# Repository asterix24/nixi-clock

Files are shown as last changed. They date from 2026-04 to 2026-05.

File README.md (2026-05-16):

# nixi-clock
My personal nixi clock with RP2040 Raspberry pico Zero



## Feature

- 4 Digit IN-4 Nixi Tube
- Raspberry Pico Zero W
- Ambient lighting sensor
- Temperature sensor
- DHT11 Sensor
- FM Radio with SkyLab chip Si470x

# Hardware

## Nixie Tube Driver
The nixie tubes needs high voltage to turn on the filament. Each tube have a commen node (Anode) and the chiper is turn on by a dedicate pin.
To drive the filament there is a dedicate mux, that could be driver with TTL voltage, using 4bit we can select 0-9 chiper.



The high voltage mux driver is connected to the 2 byte SIPO:



# Raspberry Pico WiFi Nixie Clock

| Pin # | Nome Pin (MCU) | Segnale / Net | Resistore | Note |
|---|---|---|---|---|
| 1 | GP0 | GP0 | R139 33R  | |
| 2 | GP1 | GP1 | R140 33R  | |
| 4 | GP2 | GP2 | R141 33R  | |
| 5 | GP3 | GP3 | R142 33R  | |
| 6 | GP4 | BACK_LIGHT_DATA | R100 33R  | |
| 7 | GP5 | FRONT_LIGHT_DATA | R101 33R  | |
| 9 | GP6 | HV_ENABLE | R114 33R  | High voltage boost Enable |
| 10 | GP7 | SIPO_RCLK | R104 33R  | Clock Chiper SIPO|
| 11 | GP8 | SIPO_CLR | R106 33R  | Clock Chiper SIPO|
| 12 | GP9 | SIPO_OE | R108 33R  | Clock Chiper SIPO|
| 14 | GP10 | SIPO_DATA | R111 33R  | Clock Chiper SIPO|
| 15 | GP11 | SIPO_CLK | R113 33R  | Clock Chiper SIPO|
| 16 | GP12 | 1WIRE_SENSOR | R105 33R  | |
| 17 | GP13 | B | R112 33R  | External Encoder  Signal B|
| 19 | GP14 | SWITCH0 | R109 33R  | External Encoder  Button |
| 20 | GP15 | A | R110 33R  | External Encoder  Signal A |
| 21 | GP16 | SDIO | — | |
| 22 | GP17 | SCLK | — | |
| 24 | GP18 | RST | — | |
| 25 | GP19 | GP19 | R144 33R  | |
| 26 | GP20 | BUZZER | R102 33R  | |
| 27 | GP21 | RADIO_SW | — | |
| 29 | GP22 | GP22 | R143 33R  | |
| 30 | RUN | nRESET | R103 33R  | |
| 31 | GP26 | Raw_LOUT | R133 33R  | |
| 32 | GP27 | Raw_ROUT | R132 33R  | |
| 34 | GP28 | AMB_LIGHT | R107 1k | Ambient Light Sensor  |
| 35 | AVREF | — | — | |
| 36 | 3V3 | +3.3V | — | Alimentazione |
| 37 | EN | — | — | Non connesso  |
| 39 | VSYS | — | — | Non connesso  |
| 40 | VBUS | +5V | — | Alimentazione |

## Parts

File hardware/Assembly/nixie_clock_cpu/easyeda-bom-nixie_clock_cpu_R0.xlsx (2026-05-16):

Comment | Designator | Footprint | LCSC Part #（optional）
Name | Designator | Footprint | #Column Name Error:' CODE LCSC
BUZZER | BUZ1 | buzzer_14mm_thd
10uF | C100 | 0603_[1608]
100nF | C101, C102, C105, C106, C107, C112, C113, C114 | 0603_[1608]
22nF | C103 | 0603_[1608]
1nF | C104 | 0603_[1608]
47uF | C108, C109 | [7343]_CAP_TAN_1P_2N
22pF | C110, C111 | 0603_[1608]
AMBIENT LIGHT | D100 | R5_LED_THD_A2-K1
1N4448W | D101 | SOD-123_K1-A2
+5V | D102 | 0603_[1608]_K1-A2_LED
+3.3V | D103 | 0603_[1608]_K1-A2_LED
PCB FM Antenna | JP100 | 0603_[1608]_JUMPER
270nH | L100 | 0603_[1608]
Ferrite 2,5kohm | L101, L102 | 0603_[1608]
BUZZER | P2 | HEADER_1X2_2.54MM_THD
SENSOR | P100 | HEADER_1X4_2.54MM_THD
POWER | P101 | SOCKET_2x3_2.54mm_THD
DATA | P102 | SOCKET_2x3_2.54mm_THD
ENCODER | P103 | SOCKET_2x3_2.54mm_THD
Audio | P105, P106, P107, P108 | HEADER_1X4_2.54MM_THD
BSS138 | Q1 | SOT-23
BC817 | Q100, Q101 | SOT-23
33R | R100, R101, R102, R103, R104, R105, R106, R108, R109, R110, R111, R112, R113, R114, R125, R126, R132, R133, R139, R140, R141, R142, R143, R144 | 0603_[1608]
1k | R107, R130, R135, R137, R138 | 0603_[1608]
10k | R115, R116, R117, R120, R121, R127, R128, R134 | 0603_[1608]
4k7 | R118, R119, R129 | 0603_[1608]
330R | R122, R123, R124 | 0603_[1608]
47k | R131, R136 | 0603_[1608]
RESET | S3 | TACTILE_SWITCH_6x6MM_THD
Raspberry Pico Wifi | U100 | RasberryPicoMod
Si470x | U101 | QFN-50P-20_PAD
DS18B20 | U102 | TO-92
Relay DPDT | U103 | RELAYS_DPST_THD_6x10_5.08mm
32.768kHz | Y100 | CRISTAL_R26_PAD

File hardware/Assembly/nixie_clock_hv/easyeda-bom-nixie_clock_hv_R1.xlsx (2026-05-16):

Comment | Designator | Footprint | LCSC Part #（optional）
Name | Designator | Footprint | CODE LCSC
100nF | C1, C2, C3, C4, C5, C6, C8, C9, C10, C11, C12, C13, C14, C15, C16, C17, C18, C19, C20, C21, C22, C23, C24 | 0603_[1608]
10uF | C7 | 0603_[1608]
POWER | P1 | HEADER_2X3_2.54MM_THD
DATA | P2 | HEADER_2X3_2.54MM_THD
ENCODER | P3 | HEADER_2X3_2.54MM_THD
BSS138 | Q1, Q2 | SOT-23
10k | R1, R2, R7, R8, R13, R26 | 0603_[1608]
75R | R3, R4, R5, R6 | 0603_[1608]
1k | R9, R10, R11, R12, R14, R15, R16, R17, R18, R19, R20, R21, R22, R23, R24, R25 | 0603_[1608]
22k | R27, R28, R29, R30 | AXIAL 10mm
33R | R31 | 0603_[1608]
WS2812D | U1, U2, U3, U4 | R5_RGB_LED_THD | C190565
SN74HC595D | U5, U6 | soic16
BootModule_3-9V_170V | U7 | BoostModule
K155ID1 | U8, U12, U16, U20 | DIP-16_THD
WS2812 | U9, U10, U11, U13, U14, U15, U17, U18, U19, U21, U22, U23 | LED_PLCC_RGB_4P_1010 | C5349953

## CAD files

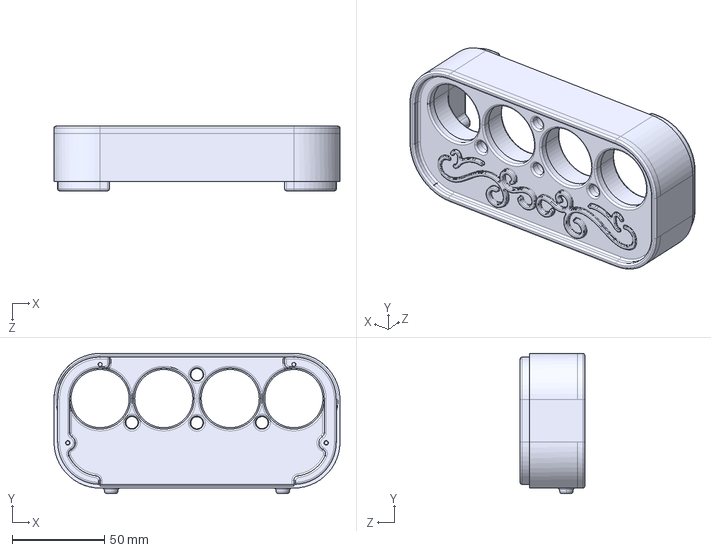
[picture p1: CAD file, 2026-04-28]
drawings/box_top.STEP
155.0 x 76.0 x 35.0 mm

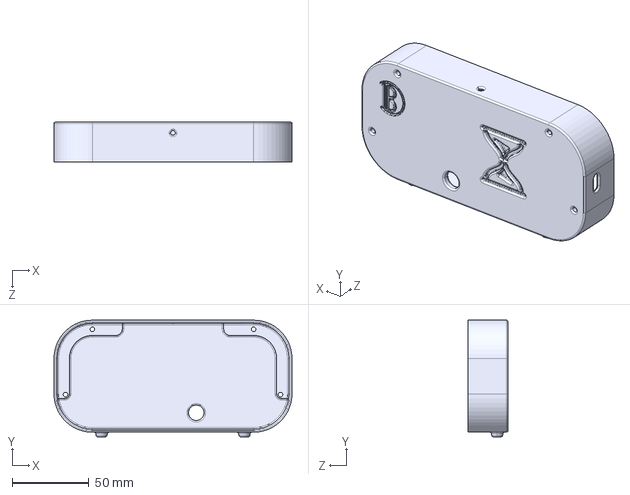
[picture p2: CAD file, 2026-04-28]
drawings/box_rear.STEP
155.0 x 76.0 x 26.0 mm

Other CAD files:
drawings/in4.dwg
drawings/box_rear.SLDPRT
drawings/box_top.SLDPRT

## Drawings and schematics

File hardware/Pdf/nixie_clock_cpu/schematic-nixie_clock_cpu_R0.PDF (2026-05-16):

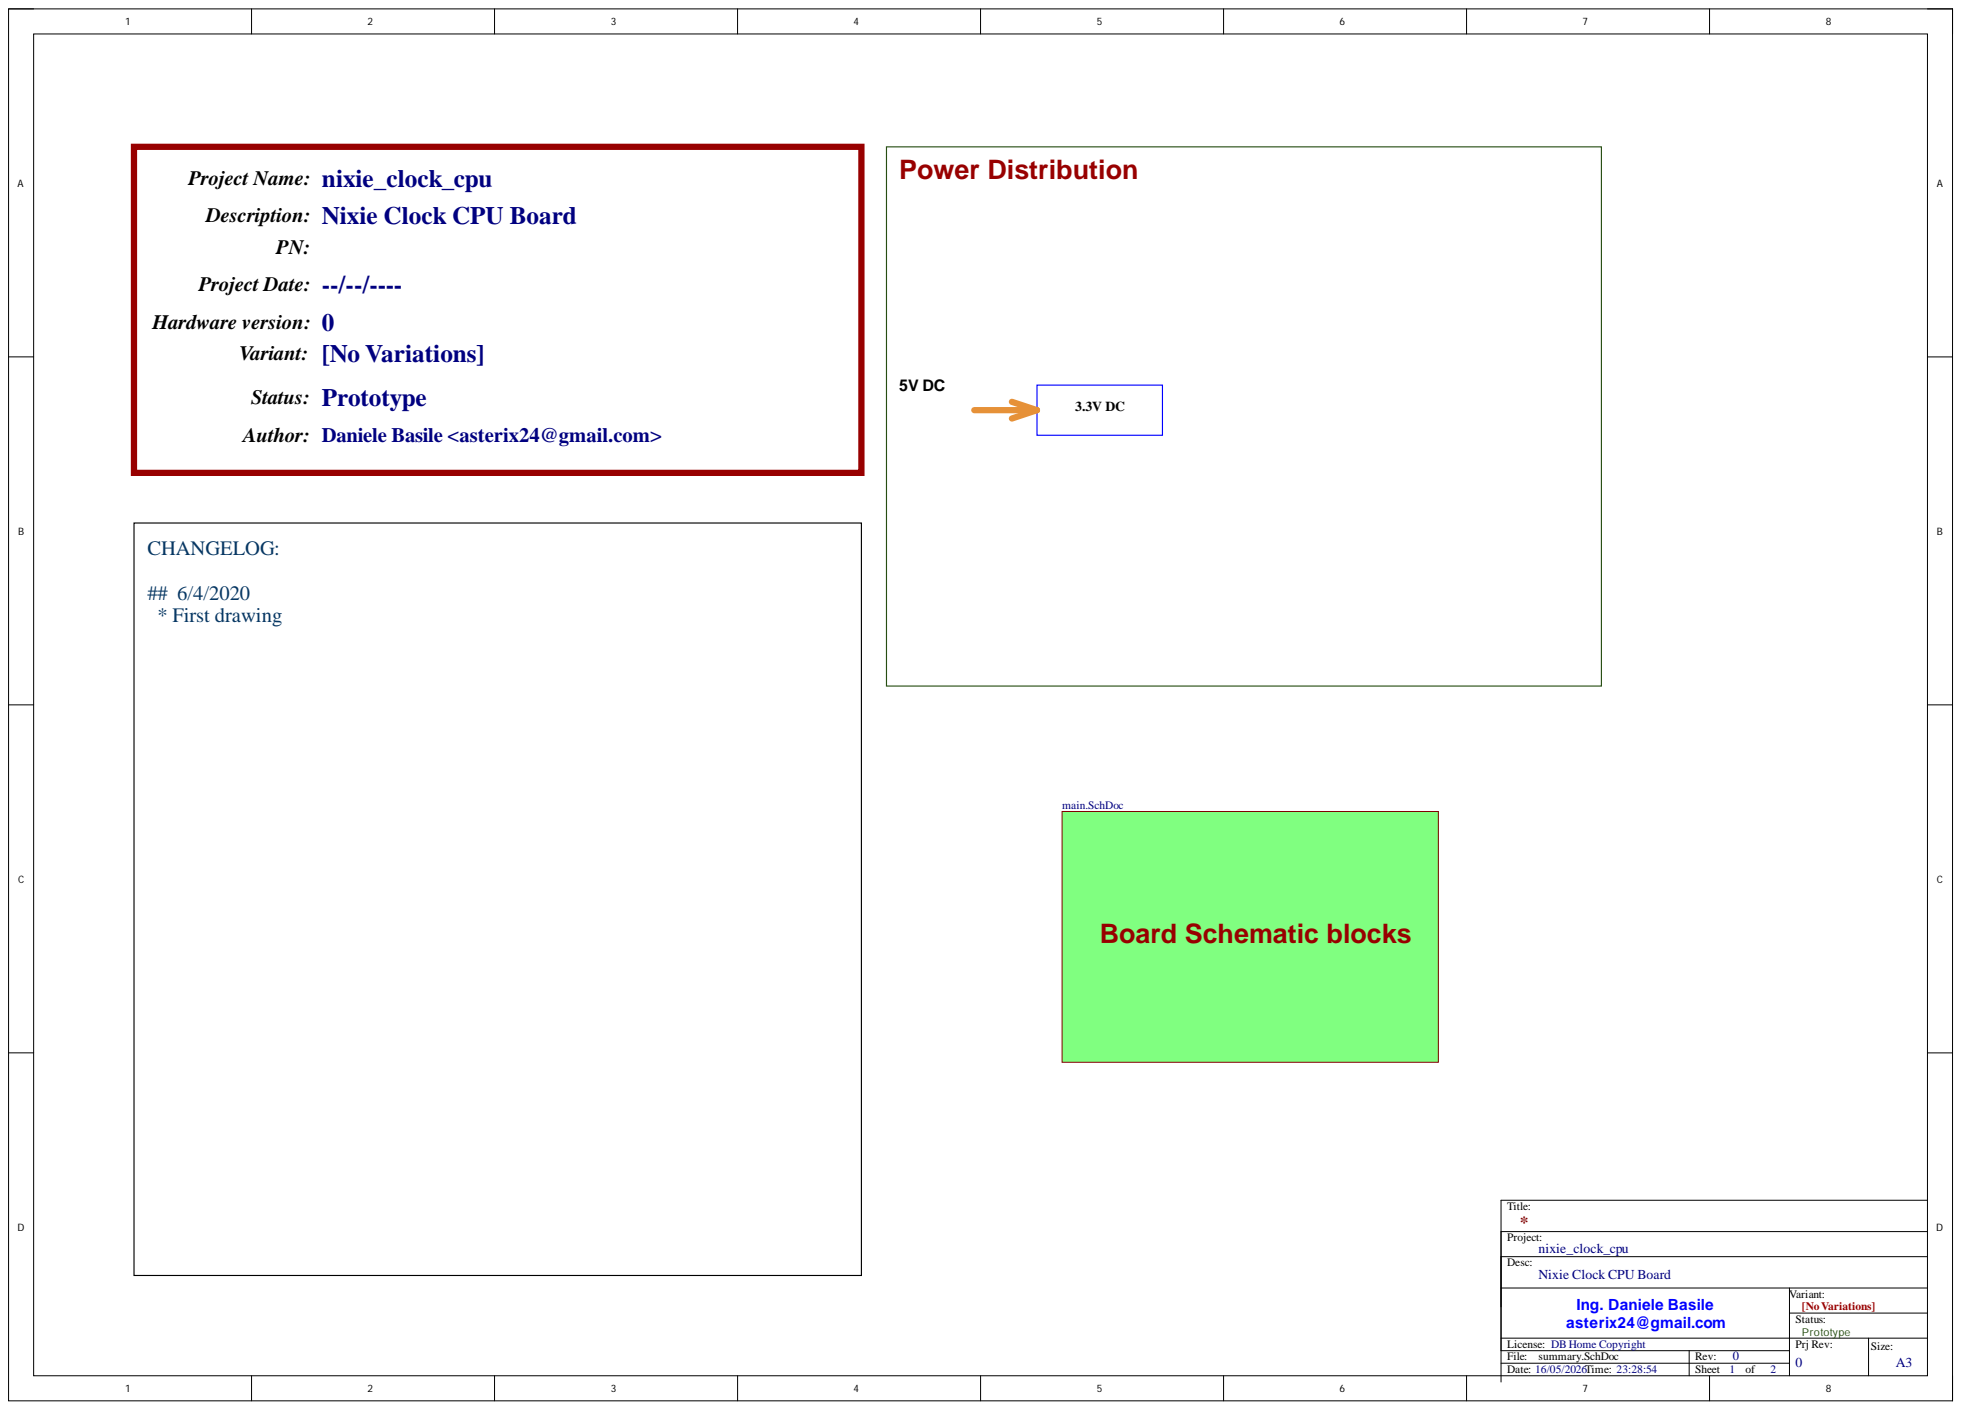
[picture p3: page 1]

Author: Daniele Basile <asterix24@gmail.com>

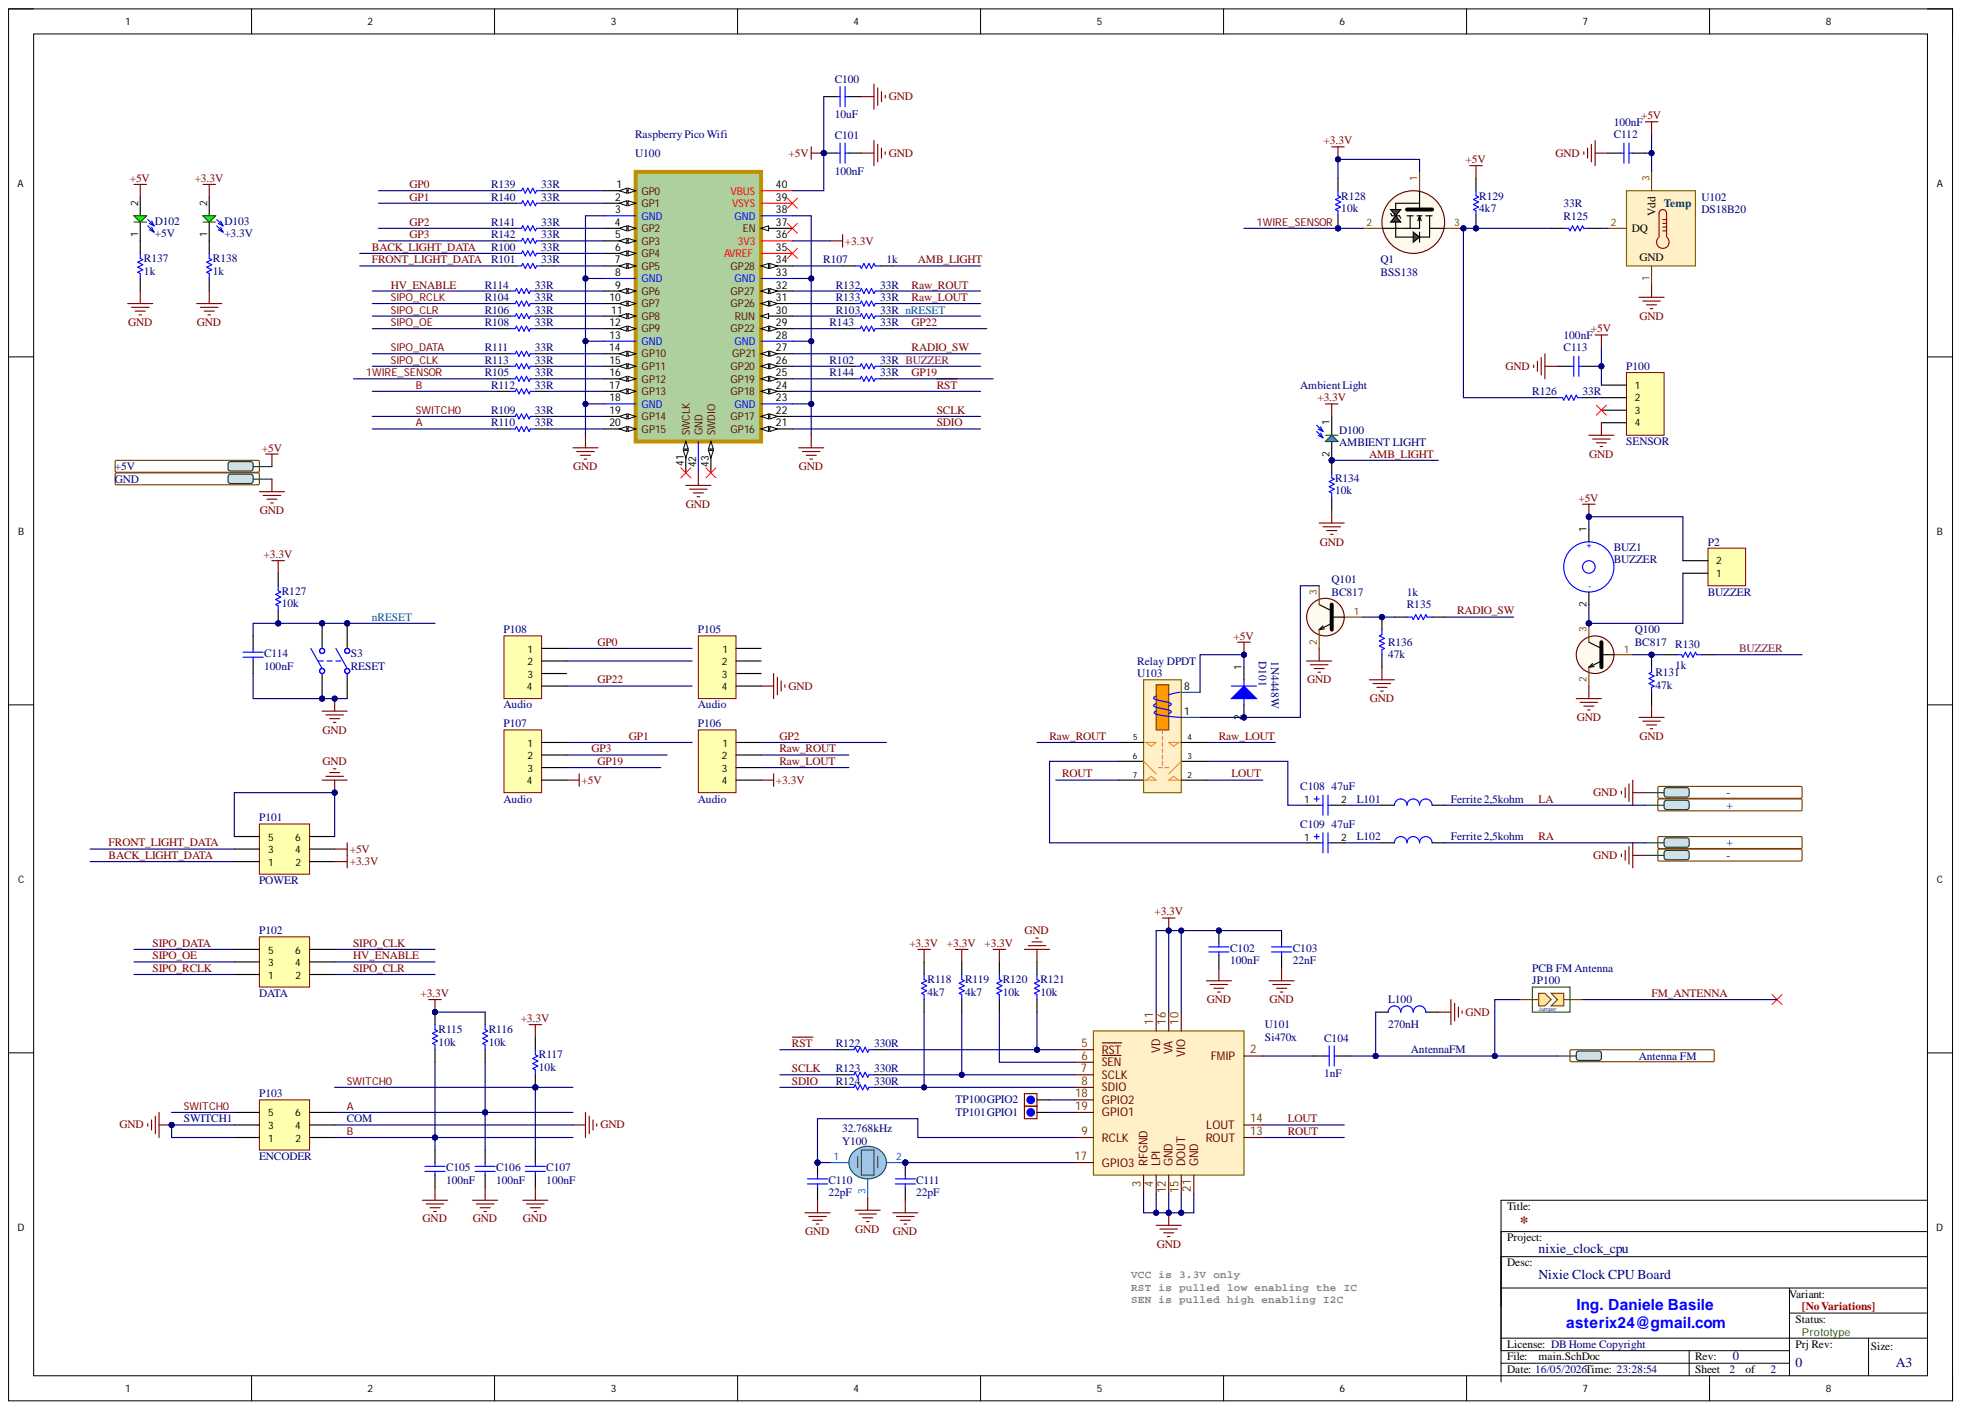
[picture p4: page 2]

GND 8 | R132 33R Raw_ROUT

GP7 10 | R133 33R Raw_LOUT
GP8 11 | R103 33R nRESET
GP9 12 | R143 33R GP22
GND 13 | RADIO_SW

GP11 15 | R102 33R BUZZER

VCC is 3.3V only
RST is pulled low enabling the IC
SEN is pulled high enabling I2C

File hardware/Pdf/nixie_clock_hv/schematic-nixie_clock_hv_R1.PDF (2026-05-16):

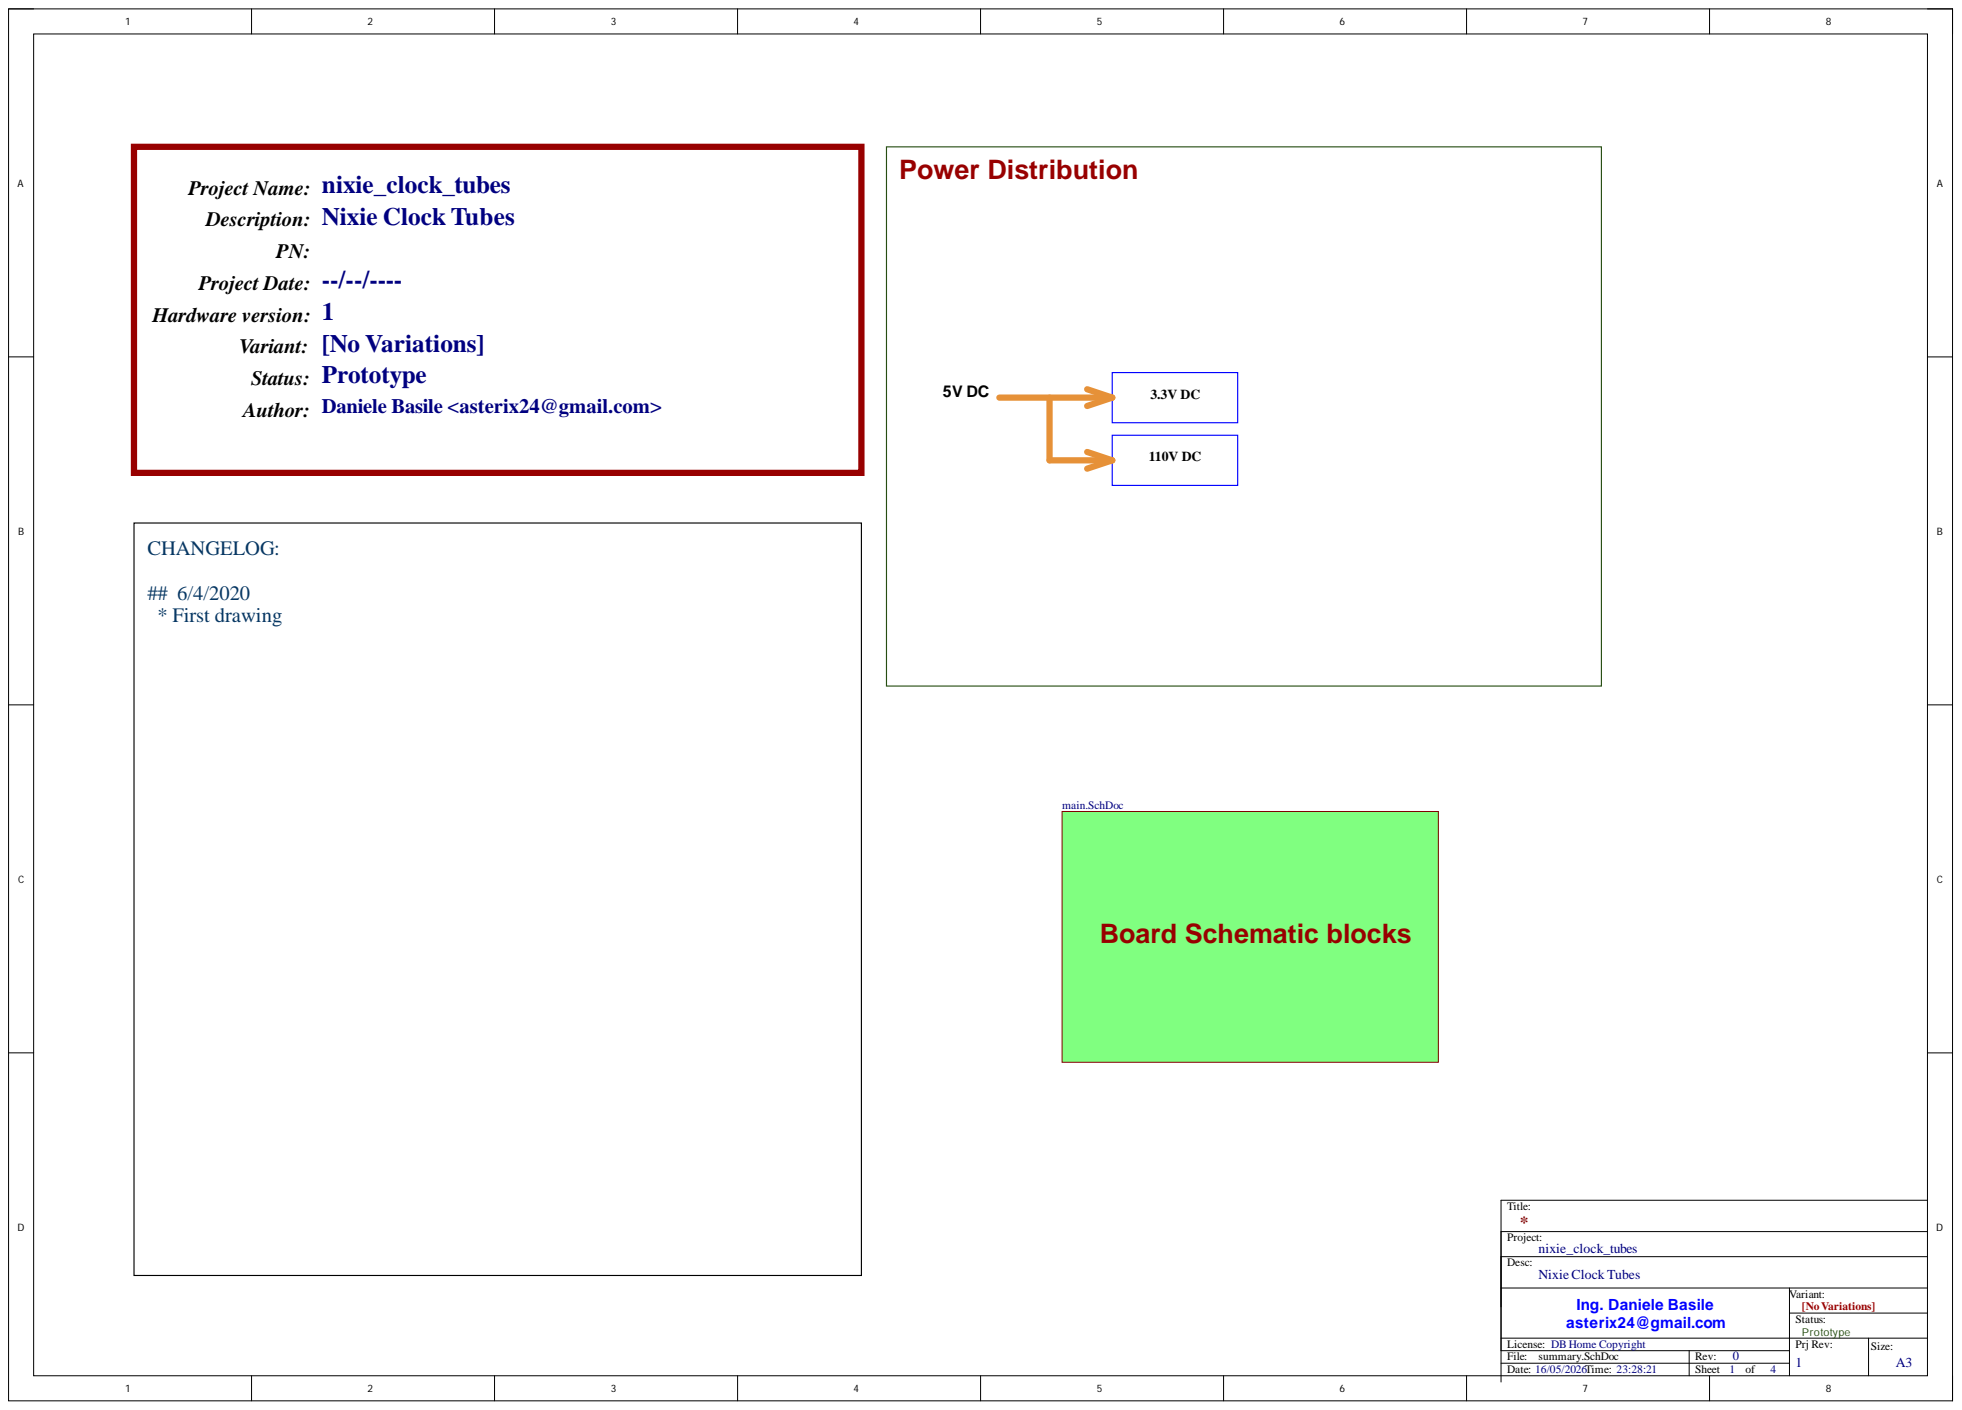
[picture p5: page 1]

Variant: [No Variations]
Author: Daniele Basile <asterix24@gmail.com>

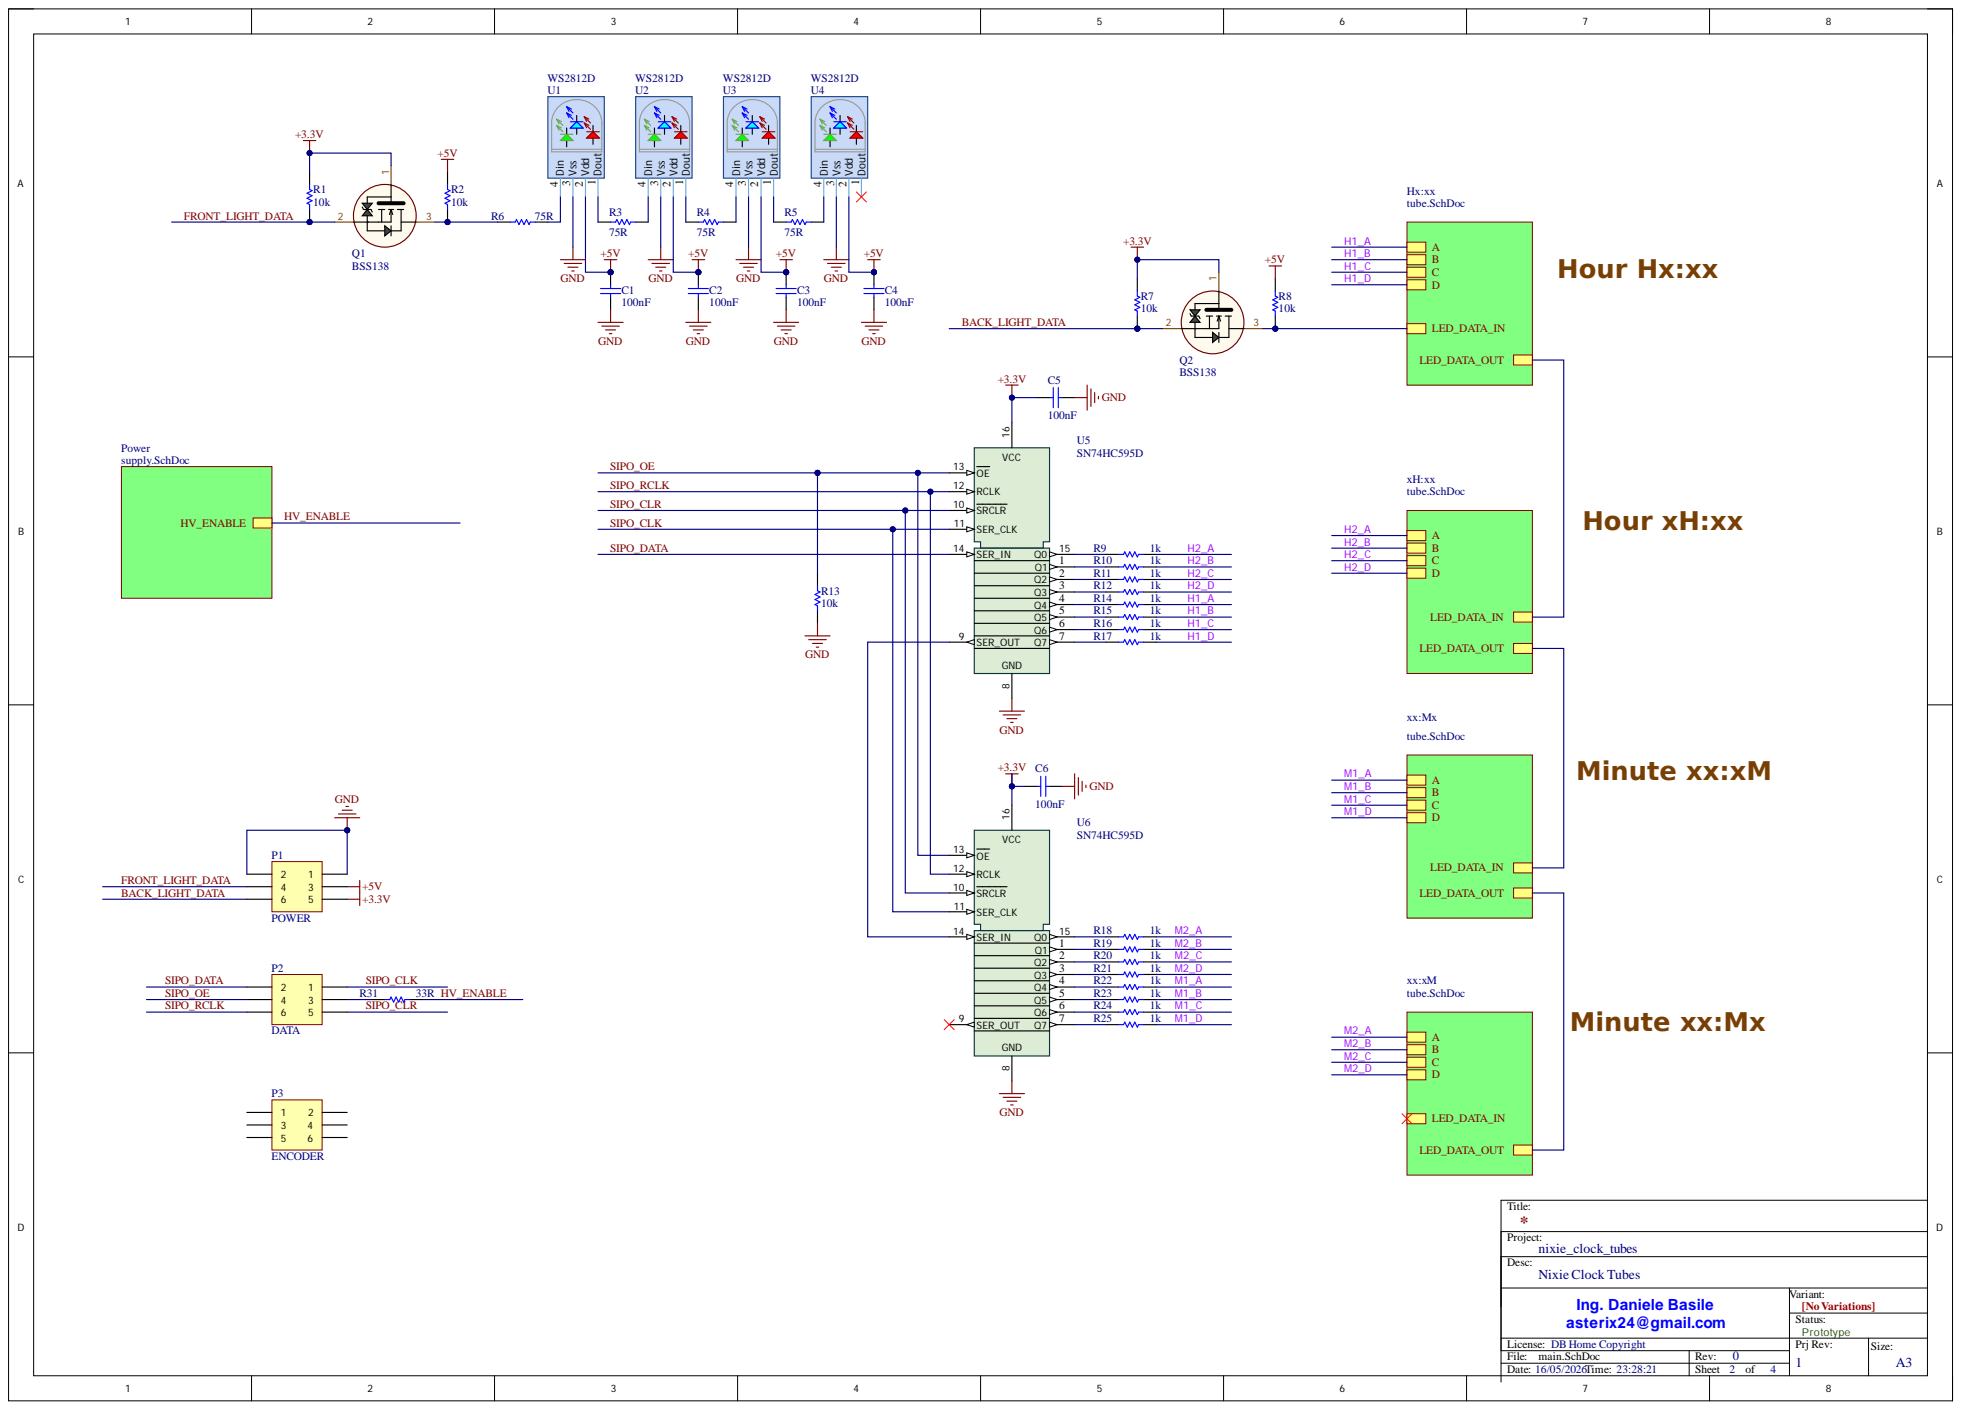
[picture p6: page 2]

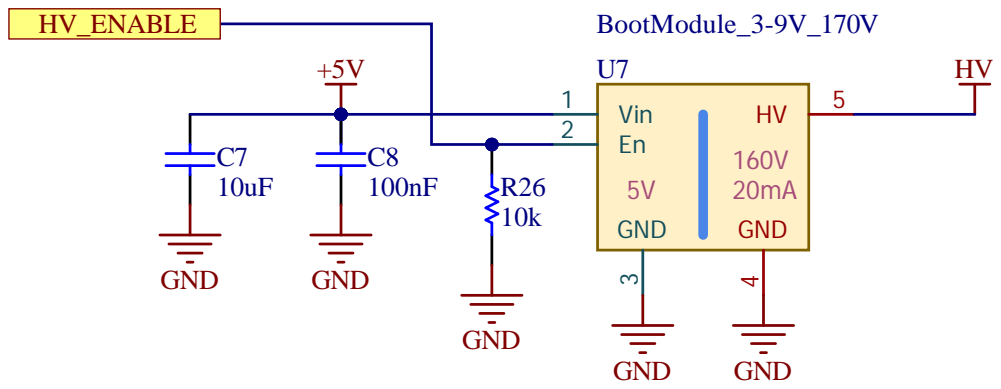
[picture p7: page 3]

Vin 1
En 2

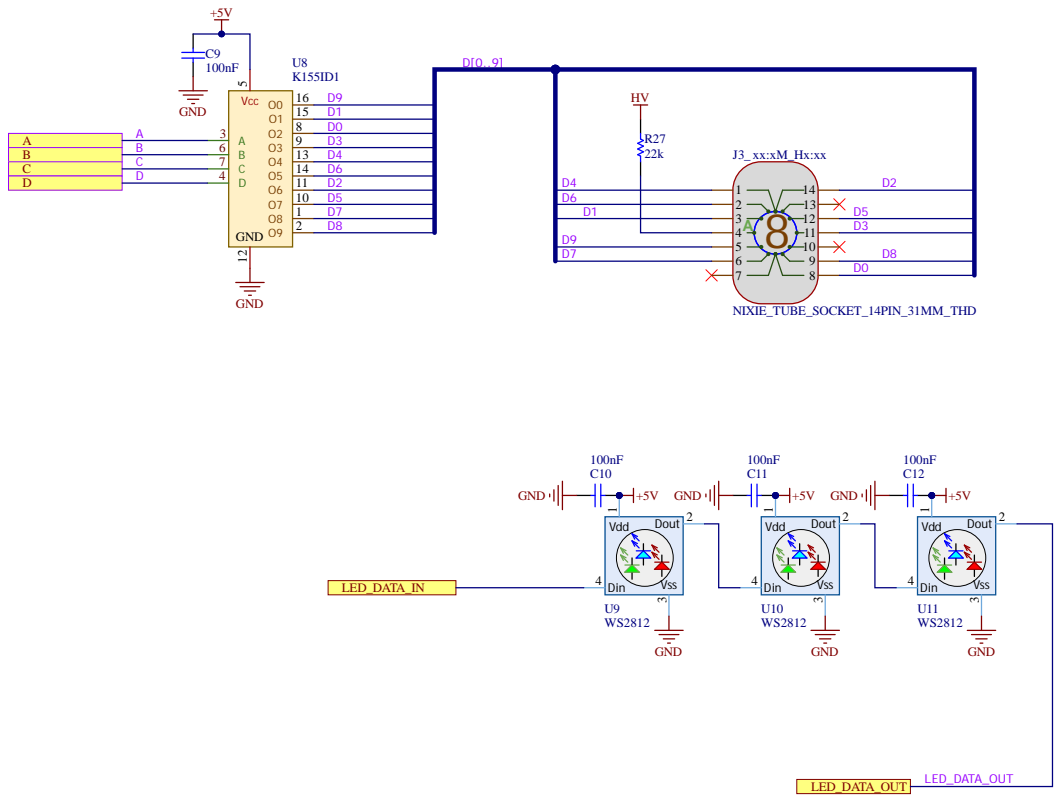
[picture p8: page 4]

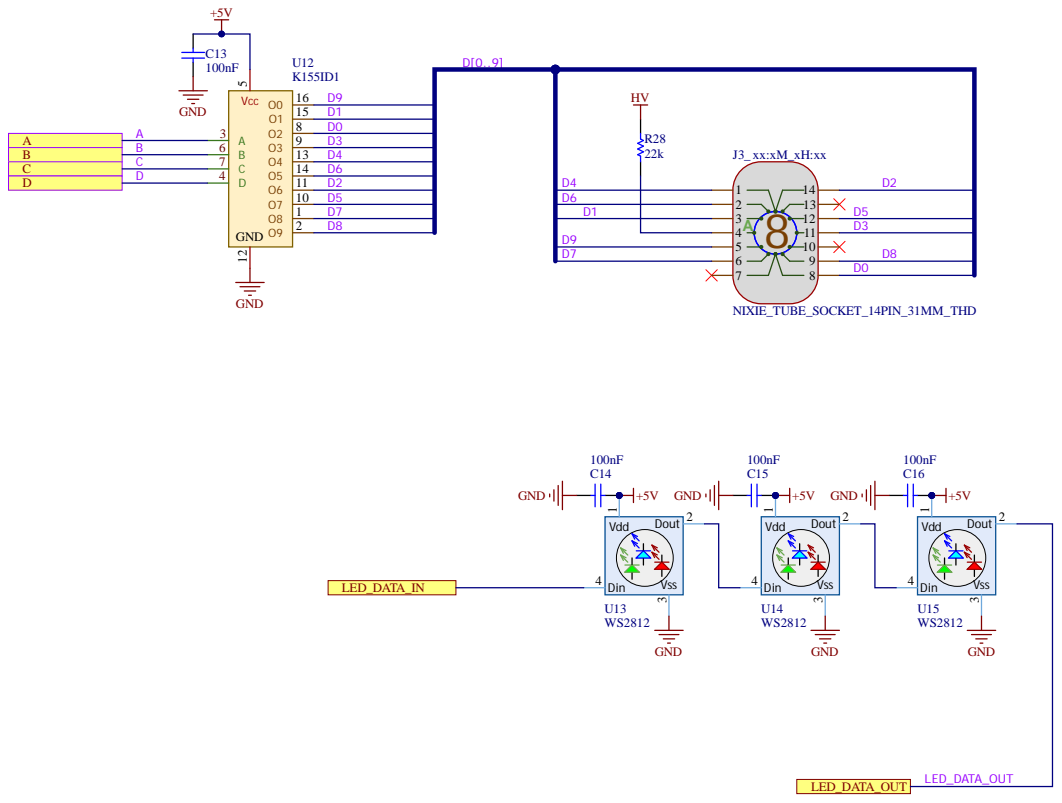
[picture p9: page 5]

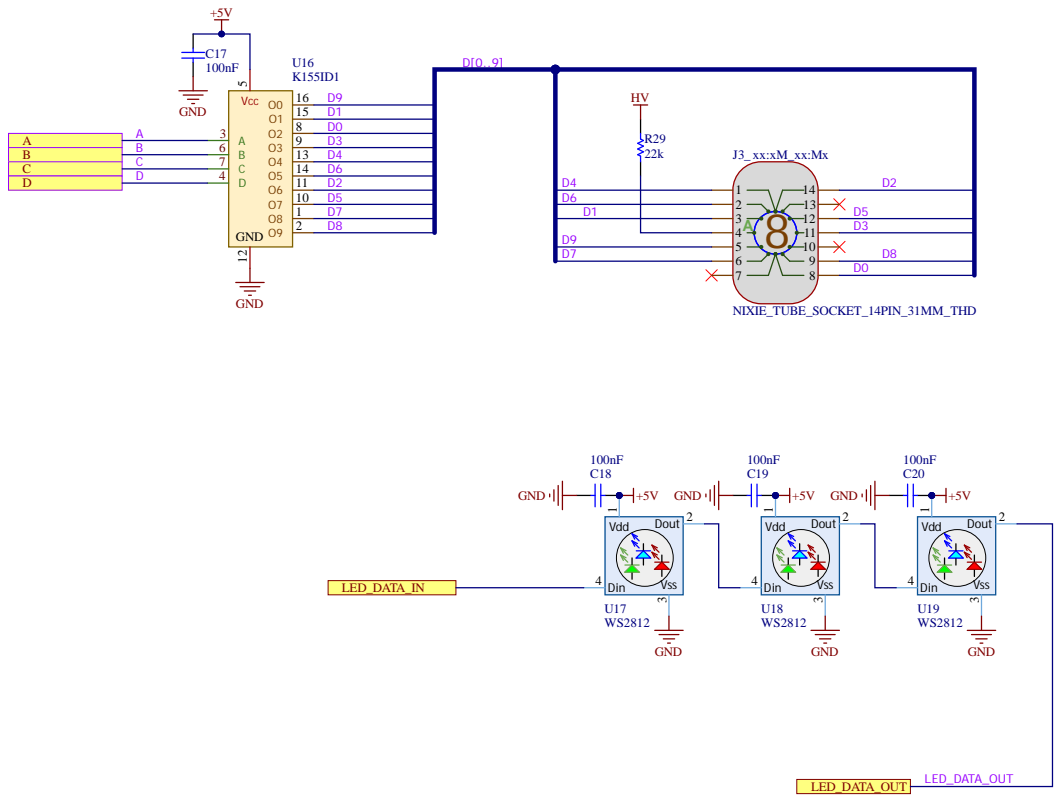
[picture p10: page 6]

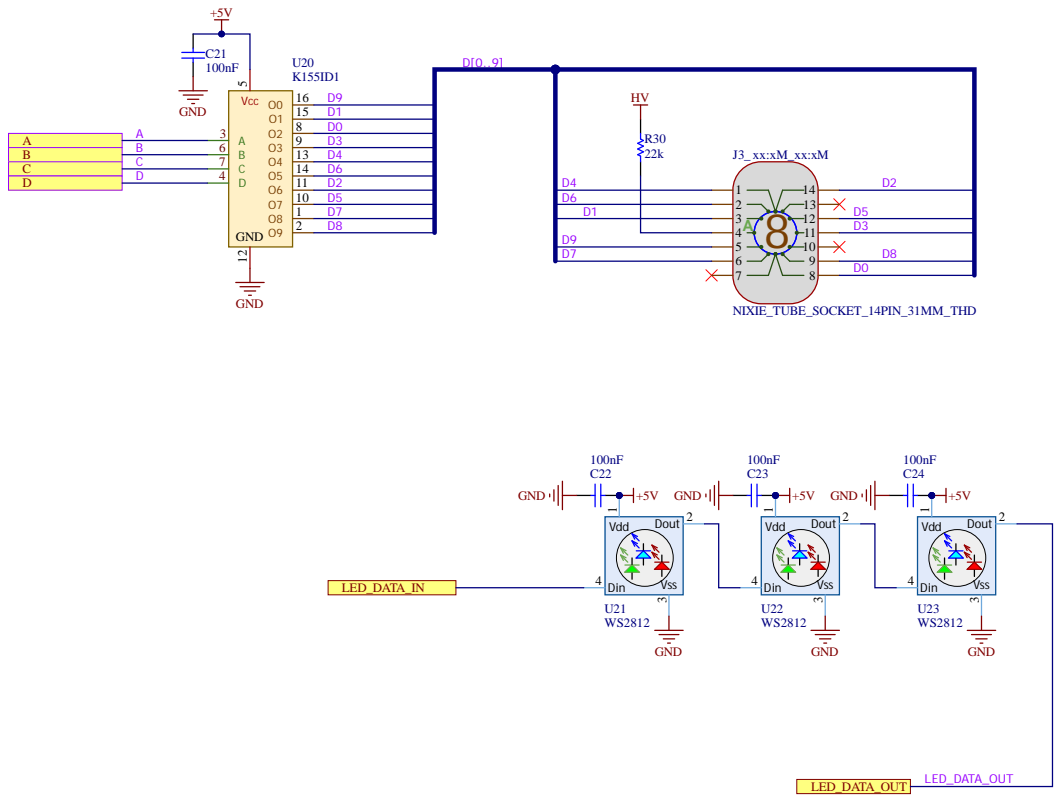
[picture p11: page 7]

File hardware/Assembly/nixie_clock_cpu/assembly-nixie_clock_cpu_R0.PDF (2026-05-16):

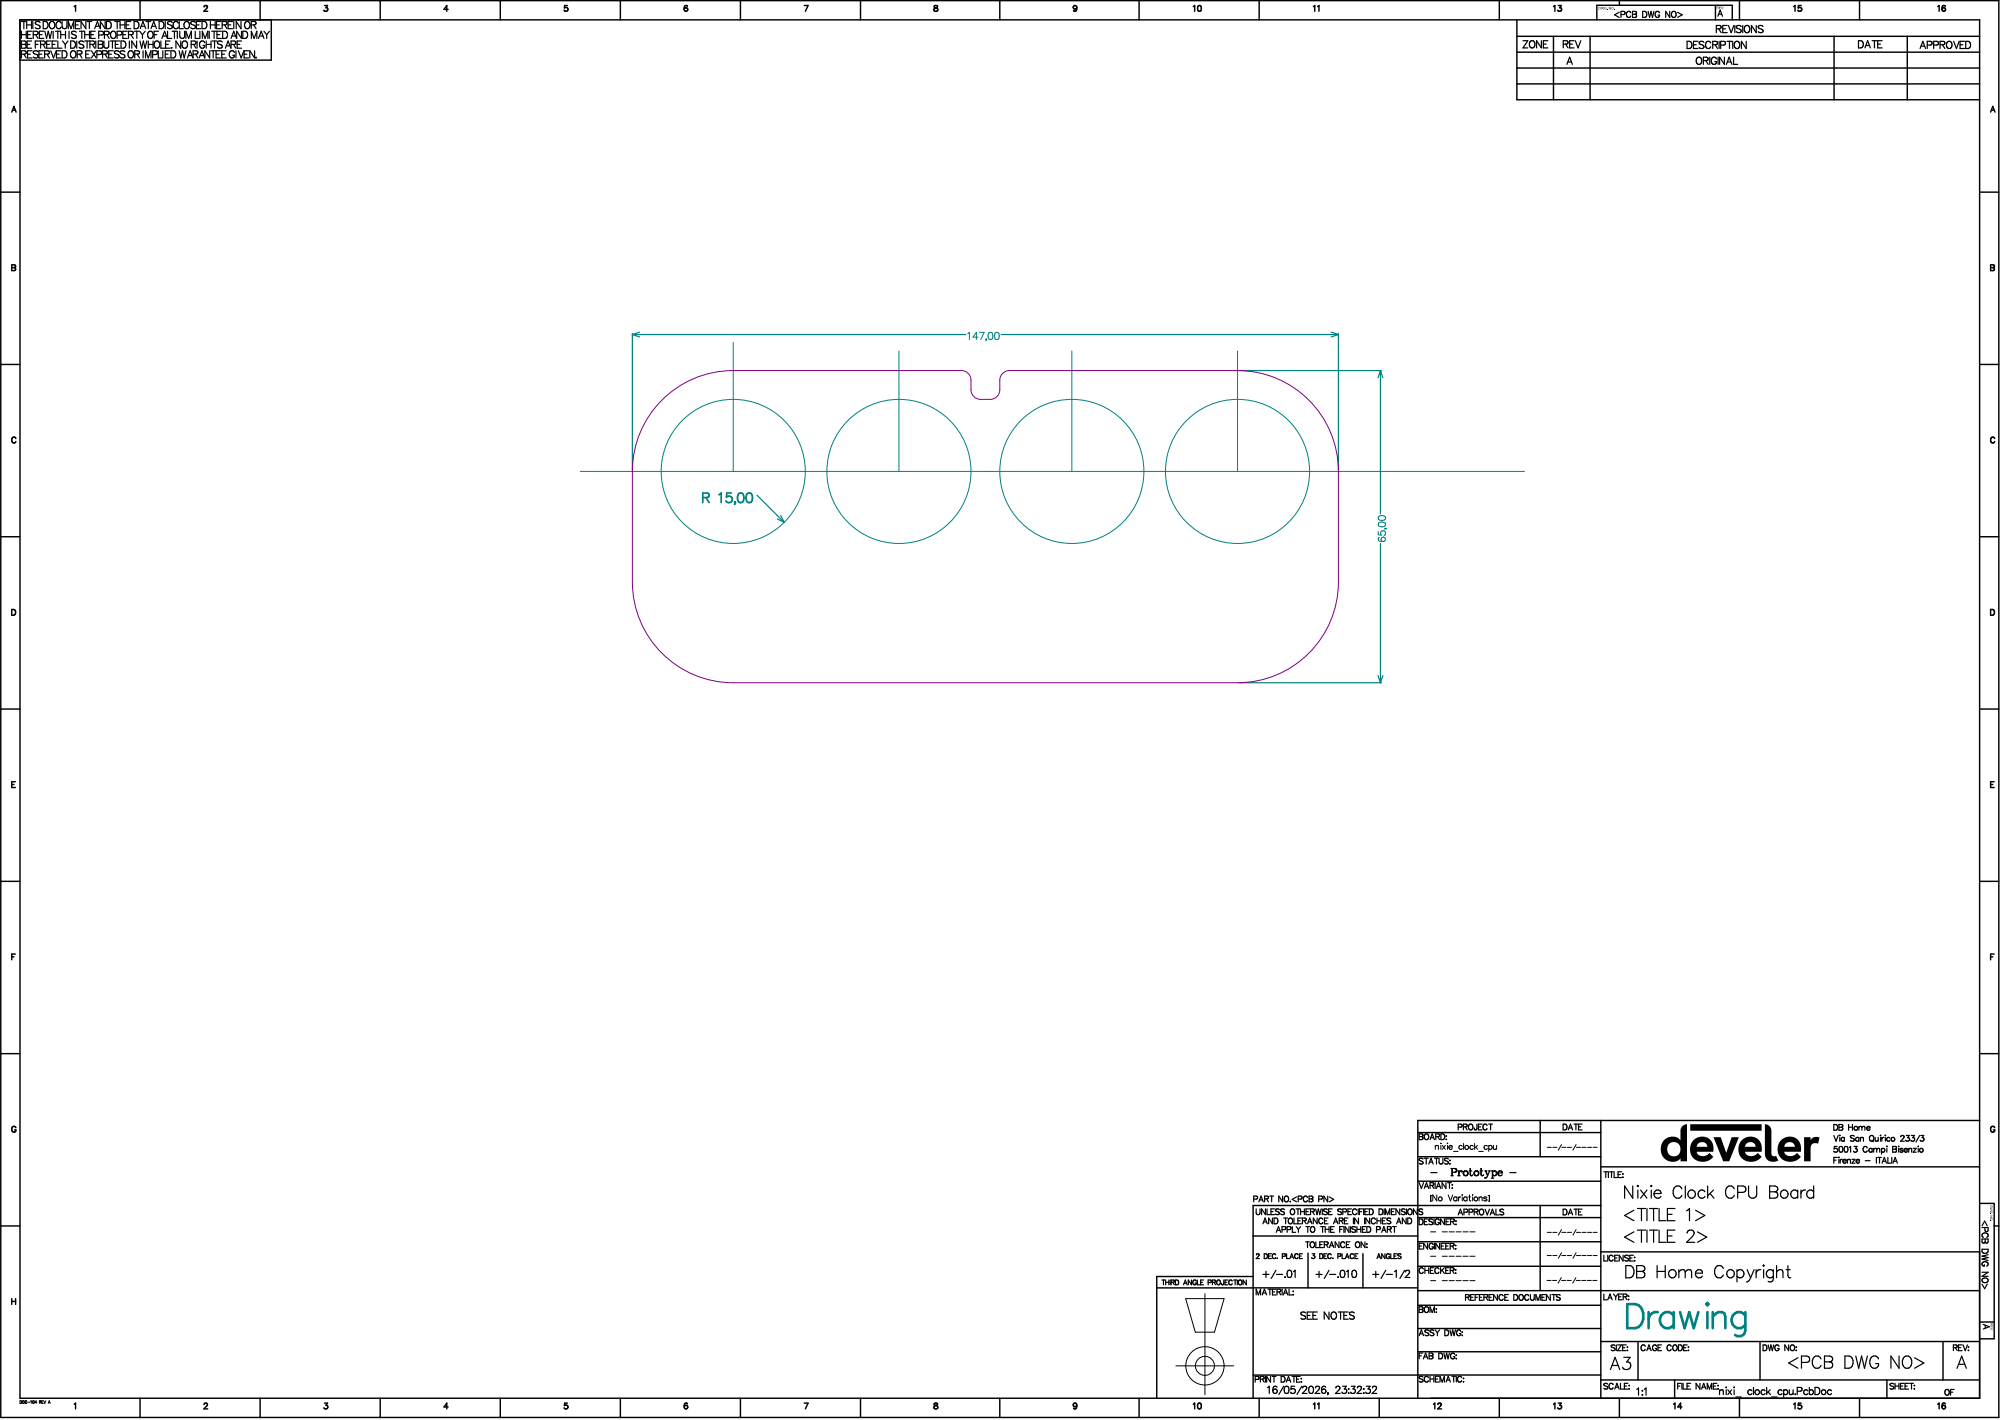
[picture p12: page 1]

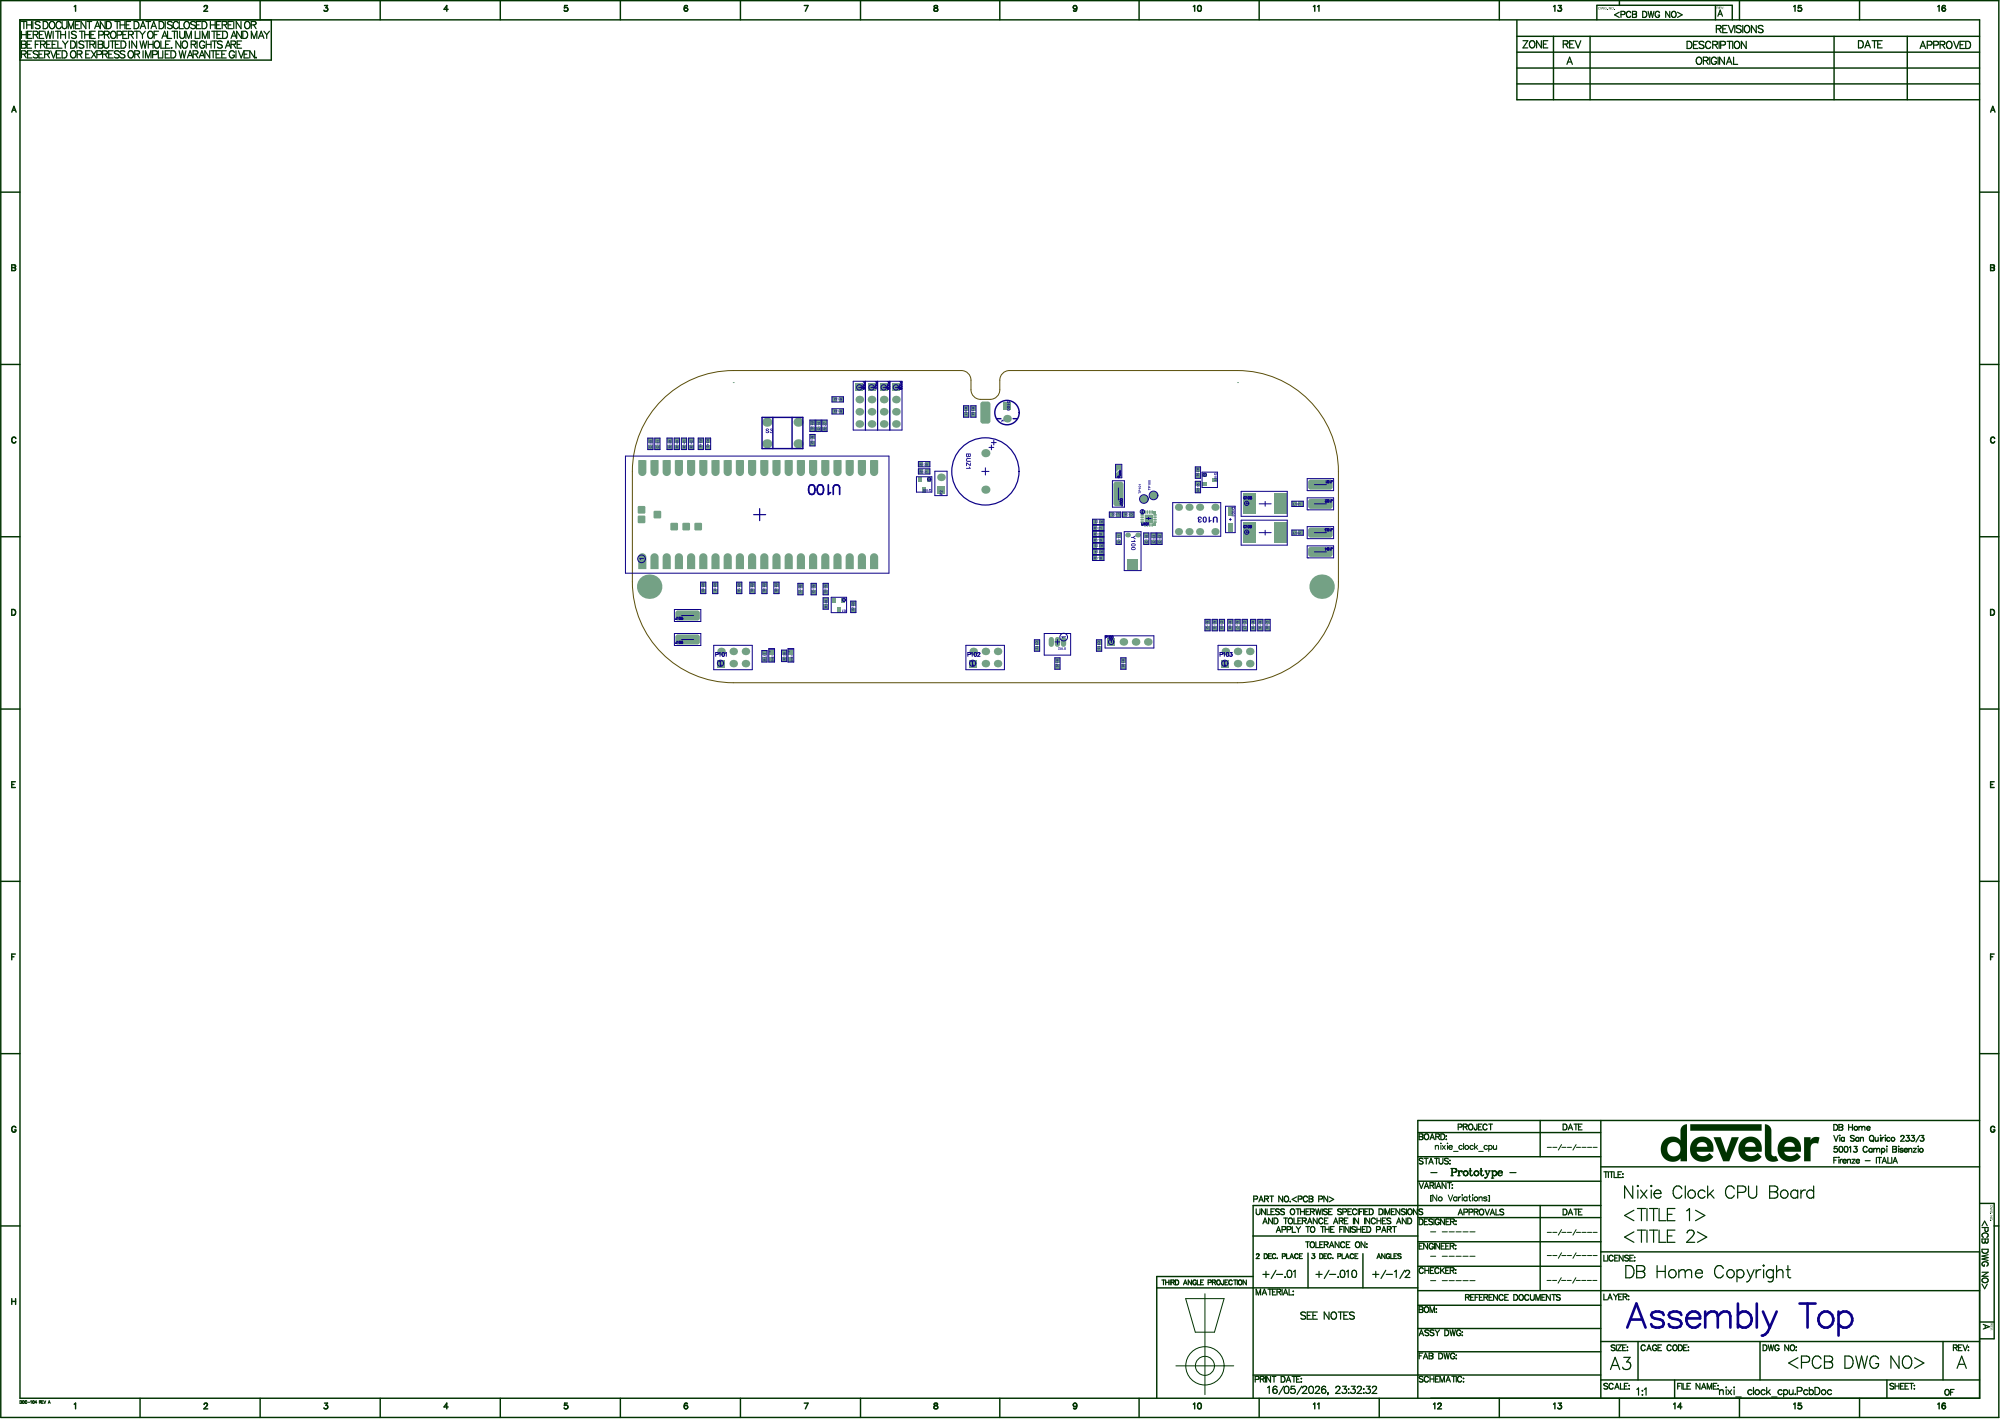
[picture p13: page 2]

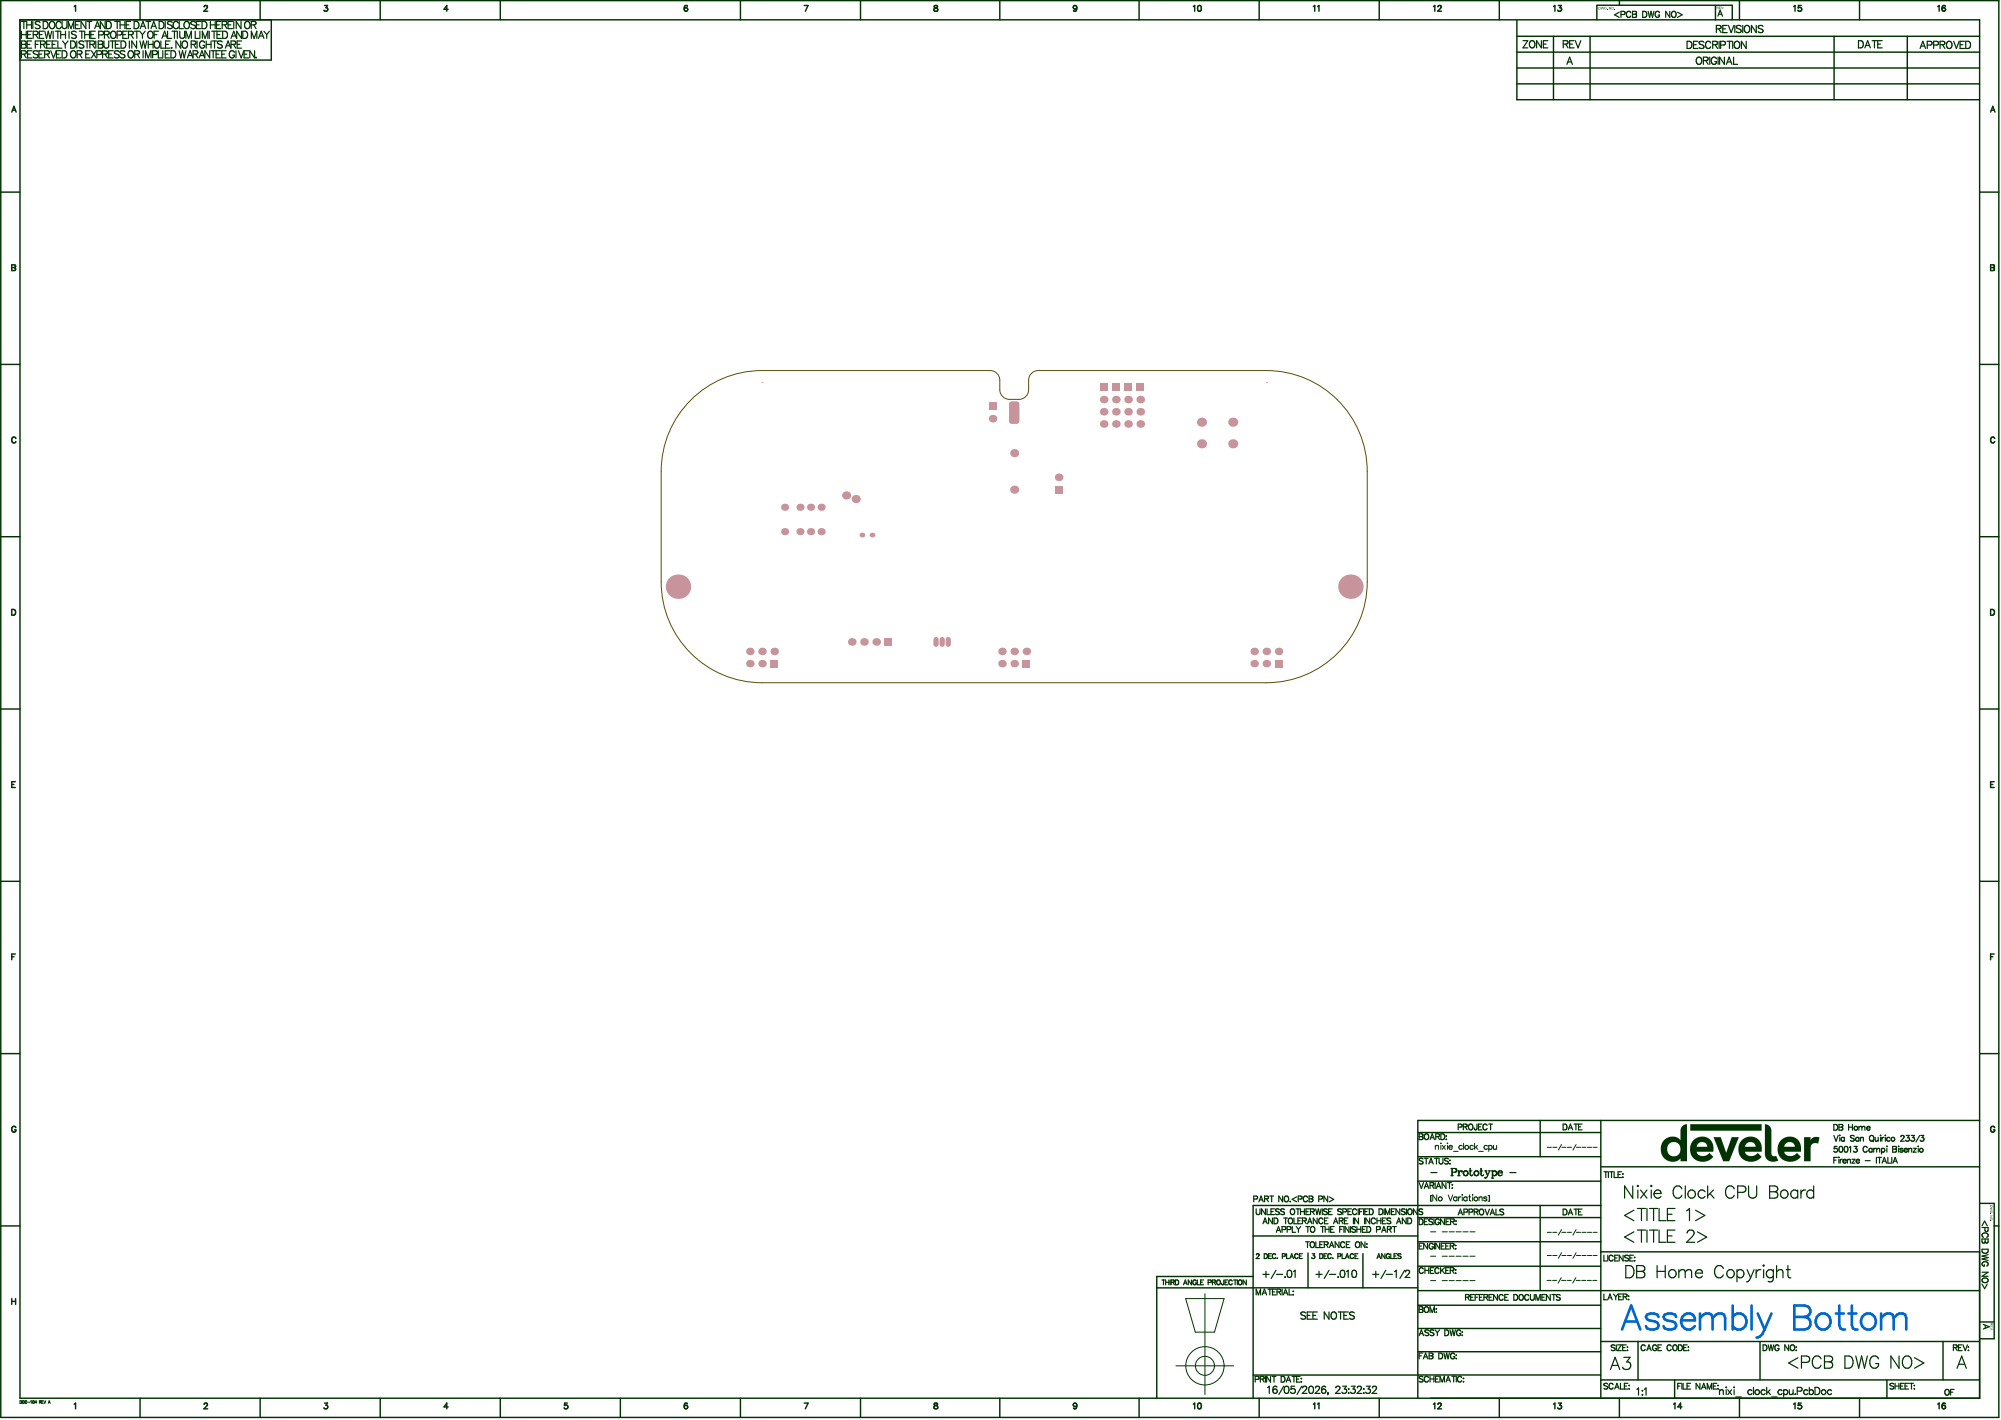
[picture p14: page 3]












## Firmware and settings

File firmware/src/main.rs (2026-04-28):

#![no_std]
#![no_main]
#![allow(async_fn_in_trait)]

use core::str::from_utf8;

use cyw43::{JoinOptions, aligned_bytes};
use cyw43_pio::{DEFAULT_CLOCK_DIVIDER, PioSpi};

use embassy_executor::Spawner;
use embassy_net::StackResources;
use embassy_net::tcp::TcpSocket;
use embassy_rp::clocks::RoscRng;
use embassy_rp::gpio::{Level, Output};
use embassy_rp::peripherals::{DMA_CH0, PIO0, SPI0, USB};
use embassy_rp::pio::{InterruptHandler, Pio};
use embassy_rp::spi::{Blocking, Phase, Polarity, Spi};
use embassy_rp::{bind_interrupts, dma, usb};
use embassy_sync::{blocking_mutex::raw::CriticalSectionRawMutex, channel::Channel};
use embedded_io_async::Write;
use static_cell::StaticCell;

use heapless::{String, Vec};
use log::{error, info};

use defmt::*;
// defmt Logging
use {defmt_rtt as _, panic_probe as _};

use nixi_clock::parser::{Command, reply};

type NetStack = embassy_net::Stack<'static>;
type NetControl = cyw43::Control<'static>;

const HELLO_MSG: &str = concat!(
    "\n== Hello, Nixi Clock v",
    env!("CARGO_PKG_VERSION"),
    " here! ==\n"
);

bind_interrupts!(struct Irqs {
    PIO0_IRQ_0 => InterruptHandler<PIO0>;
    DMA_IRQ_0 => dma::InterruptHandler<DMA_CH0>;
    USBCTRL_IRQ => usb::InterruptHandler<USB>;
});

const WIFI_NETWORK: &str = env!("SSID");
const WIFI_PASSWORD: &str = env!("PASSWORD");

static PROTO_PARSE: Channel<CriticalSectionRawMutex, String<128>, 2> = Channel::new();
static PROTO_RET: Channel<CriticalSectionRawMutex, String<64>, 2> = Channel::new();
static SIPO_OUT: Channel<CriticalSectionRawMutex, u8, 2> = Channel::new();

#[embassy_executor::task]
async fn sipo_task(mut sipo: Spi<'static, SPI0, Blocking>, mut latch: Output<'static>) {
    loop {
        let data = SIPO_OUT.receive().await;
        if let Ok(_) = sipo.blocking_write(&mut [data]) {
            embassy_time::Timer::after_micros(1).await;
            latch.set_level(Level::High);
            embassy_time::Timer::after_micros(1).await;
            latch.set_level(Level::Low);
        } else {
            error!("unable to write sipo");
        }

        embassy_time::Timer::after_millis(500).await;
    }
}

#[embassy_executor::task]
async fn logger_task(usb: embassy_rp::Peri<'static, embassy_rp::peripherals::USB>) {
    let driver = embassy_rp::usb::Driver::new(usb, Irqs);
    embassy_usb_logger::run!(1024, log::LevelFilter::Info, driver);
}

#[embassy_executor::task]
async fn cyw43_task(
    runner: cyw43::Runner<'static, cyw43::SpiBus<Output<'static>, PioSpi<'static, PIO0, 0>>>,
) -> ! {
    runner.run().await
}

#[embassy_executor::task]
async fn net_task(mut runner: embassy_net::Runner<'static, cyw43::NetDriver<'static>>) -> ! {
    runner.run().await
}

#[embassy_executor::task]
async fn clock_task() -> ! {
    let mut data: u8 = 0;
    let sipo_out = SIPO_OUT.dyn_sender();
    loop {
        embassy_time::Timer::after_millis(100).await;
        sipo_out.send(data).await;
        if data == 0 {
            data = 1;
        }
        data = data << 1;
    }
}

#[embassy_executor::task]
async fn connection_task(stack: &'static NetStack, mut control: NetControl) -> ! {
    loop {
        if !stack.is_link_up() {
            while let Err(err) = control
                .join(WIFI_NETWORK, JoinOptions::new(WIFI_PASSWORD.as_bytes()))
                .await
            {
                info!("join failed: {:?}", err);
            }
            info!("waiting for link...");
            stack.wait_link_up().await;

            info!("waiting for DHCP...");
            stack.wait_config_up().await;

            // And now we can use it!
            info!("Stack is up!");
            if let Some(config) = stack.config_v4() {
                info!("IP: {}", config.address);
            }
            control.gpio_set(1, true).await;
        }
        embassy_time::Timer::after_secs(5).await;
    }
}

#[embassy_executor::task]
async fn shell_task(stack: &'static NetStack) -> ! {
    let mut rx_buffer = [0; 4096];
    let mut tx_buffer = [0; 4096];
    let mut tmp_buffer = [0; 4096];

    loop {
        let mut socket = TcpSocket::new(*stack, &mut rx_buffer, &mut tx_buffer);
        socket.set_timeout(Some(embassy_time::Duration::from_secs(60)));
        if let Err(e) = socket.accept(20000).await {
            info!("accept error: {:?}", e);
            continue;
        }
        if let Err(e) = socket.write_all(HELLO_MSG.as_bytes()).await {
            info!("write error: {:?}", e);
        }
        loop {
            let n = match socket.read(&mut tmp_buffer).await {
                Ok(0) => {
                    info!("read EOF");
                    break;
                }
                Ok(n) => n,
                Err(e) => {
                    info!("read error: {:?}", e);
                    break;
                }
            };

            info!("rxd {}", from_utf8(&tmp_buffer[..n]).unwrap());

            PROTO_PARSE
                .send(String::from_utf8(Vec::from_slice(&tmp_buffer[..n]).unwrap()).unwrap())
                .await;

            let ret_str = PROTO_RET.receive().await;
            if let Err(e) = socket.write_all(ret_str.as_bytes()).await {
                info!("write error: {:?}", e);
                break;
            }
        }
    }
}

#[embassy_executor::main]
async fn main(spawner: Spawner) {
    let p = embassy_rp::init(Default::default());

    spawner.spawn(unwrap!(logger_task(p.USB)));

    let mut rng = RoscRng;

    let fw = aligned_bytes!("../firmware/43439A0.bin");
    let clm = aligned_bytes!("../firmware/43439A0_clm.bin");
    let nvram = aligned_bytes!("../firmware/nvram_rp2040.bin");

    let mut led = Output::new(p.PIN_22, Level::Low);
    let pwr = Output::new(p.PIN_23, Level::Low);
    let cs = Output::new(p.PIN_25, Level::High);
    let mut pio = Pio::new(p.PIO0, Irqs);
    let spi = PioSpi::new(
        &mut pio.common,
        pio.sm0,
        DEFAULT_CLOCK_DIVIDER,
        pio.irq0,
        cs,
        p.PIN_24,
        p.PIN_29,
        dma::Channel::new(p.DMA_CH0, Irqs),
    );

    // Sipo and Piso constants
    //sipoEnable machine.Pin = machine.GPIO15
    //sipoLoad               = machine.GPIO17
    //sipoClk                = machine.GPIO18
    //sipoMosi               = machine.GPIO19
    //pisoMiso               = machine.GPIO16
    //pisoLoad               = machine.GPIO14
    let sipo_load = Output::new(p.PIN_17, Level::Low);
    let mut sipo_en = Output::new(p.PIN_15, Level::High);
    let mut sipo_config = embassy_rp::spi::Config::default();
    sipo_config.frequency = 1_000_000;
    sipo_config.phase = Phase::CaptureOnFirstTransition;
    sipo_config.polarity = Polarity::IdleLow;
    let sipo = Spi::new_blocking_txonly(p.SPI0, p.PIN_18, p.PIN_19, sipo_config);
    sipo_en.set_level(Level::Low);

    static STATE: StaticCell<cyw43::State> = StaticCell::new();
    let state = STATE.init(cyw43::State::new());
    let (net_device, mut control, runner) = cyw43::new(state, pwr, spi, fw, nvram).await;

    spawner.spawn(unwrap!(cyw43_task(runner)));

    control.init(clm).await;
    control
        .set_power_management(cyw43::PowerManagementMode::PowerSave)
        .await;

    let config = embassy_net::Config::dhcpv4(Default::default());

    // Init network stack
    static RESOURCES: StaticCell<StackResources<3>> = StaticCell::new();
    static STACK: StaticCell<NetStack> = StaticCell::new();
    let (stack, runner) = embassy_net::new(
        net_device,
        config,
        RESOURCES.init(StackResources::new()),
        rng.next_u64(),
    );

    let stack = STACK.init(stack);

    spawner.spawn(unwrap!(net_task(runner)));
    spawner.spawn(unwrap!(connection_task(stack, control)));
    spawner.spawn(unwrap!(shell_task(stack)));
    spawner.spawn(unwrap!(sipo_task(sipo, sipo_load)));
    spawner.spawn(unwrap!(clock_task()));

    let in_chan = PROTO_PARSE.dyn_receiver();
    let out_chan = PROTO_RET.dyn_sender();
    let sipo_out = SIPO_OUT.dyn_sender();

    loop {
        let return_msg = match Command::try_from(in_chan.receive().await) {
            Ok(cmd) => match cmd {
                Command::Version => reply(env!("CARGO_PKG_VERSION"), true),
                Command::Out { mask } => {
                    sipo_out.send(mask).await;
                    reply("", true)
                }
                _ => reply("Invalid Command", true),
            },
            Err(_) => reply("Uknow Connand: {}", true),
        };
        out_chan.send(return_msg).await;
        led.toggle();
    }
}

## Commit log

2026-04-28 add 3d model of shell
    [box_rear.SLDPRT, box_rear.STEP, box_top.SLDPRT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]
2026-04-28 Clean up
    [bom-nixie_clock_R0.csv, bom-nixie_clock_cpu_R0.csv, develer_2L_Ax_panel.PcbDoc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]
2026-05-16 Reoder and clean up
    [develer_2L_Ax_panel.PcbDoc, main.SchDoc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]
2026-05-16 Update 3d pcb models
2026-05-16 Update output files
    [bom-nixie_clock_R0.csv, bom-nixie_clock_cpu_R0.csv, bom-nixie_clock_cpu_R0.xlsx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]
2026-05-16 Rename and cleanup
    [main.SchDoc, nixie_clock_hv.PrjPcb, summary.SchDoc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]
2026-05-16 Clean up ad rename
    [nixie_clock_cpu.PrjPcb]
2026-05-16 Add kicad converterd prj
    [main.kicad_sch, nixie_clock_cpu.kicad_sch, nixie_clock_hv.kicad_sch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]
2026-05-16 Add pinout table for Raspberry Pico WiFi Nixie Clock
